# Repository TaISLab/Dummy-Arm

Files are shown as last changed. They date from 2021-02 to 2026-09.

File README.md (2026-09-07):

# Modular and sensorized dummy-arm

Desing of a sensorized dummy arm for human-robot interaction experiments.
The system icnludes a 3D printed arm with 10k linear rotary potentiometers and a DAQ based on a Arduino Mega which provides joint values at a rate of 100 Hz.
This repository includes both the STL for the arm components and the firmware dor the data acquisition system.

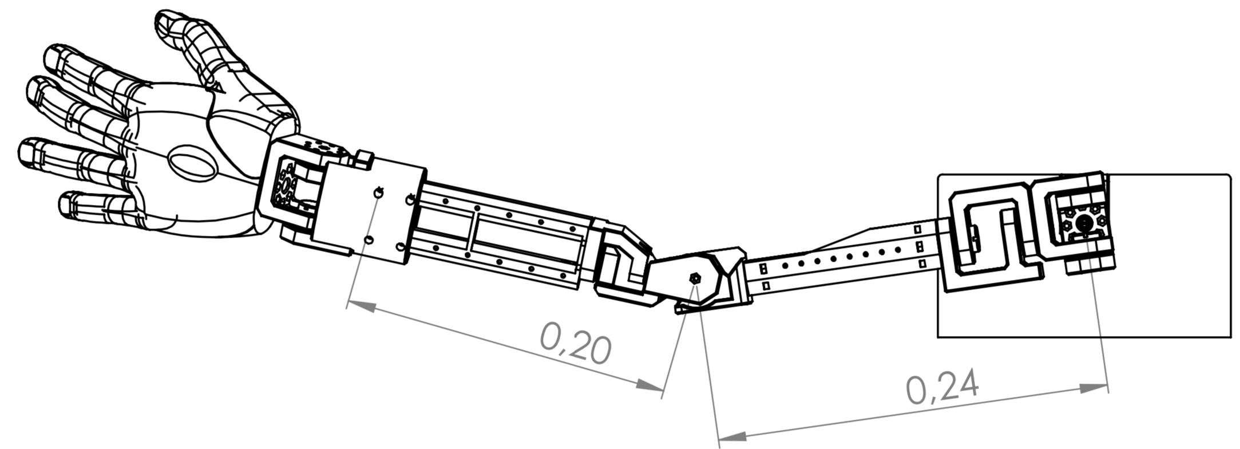
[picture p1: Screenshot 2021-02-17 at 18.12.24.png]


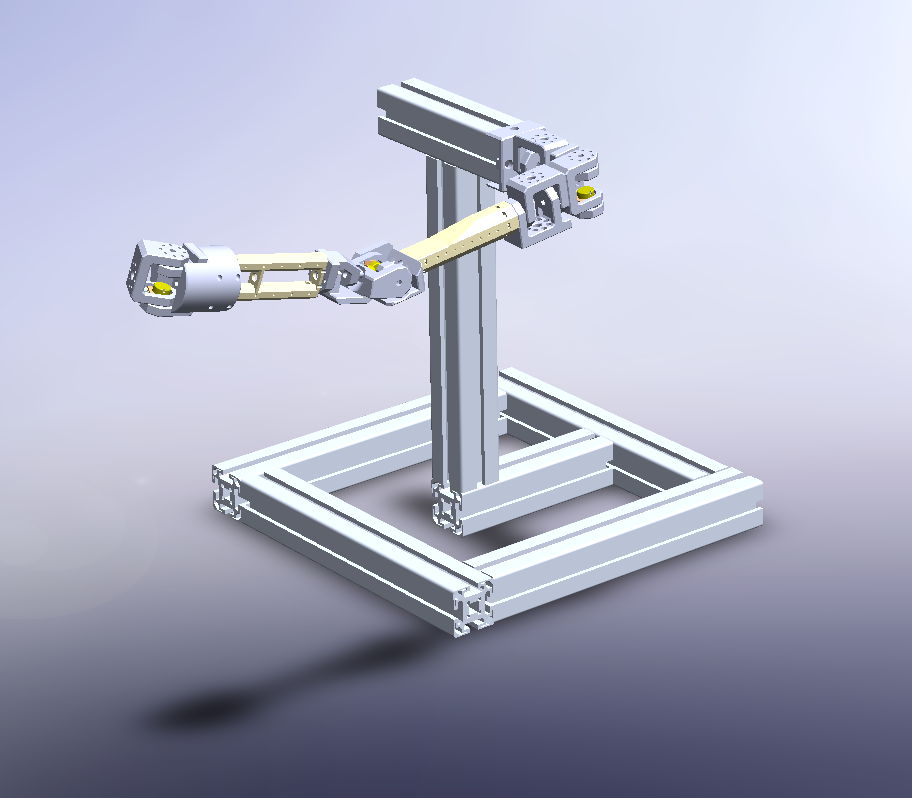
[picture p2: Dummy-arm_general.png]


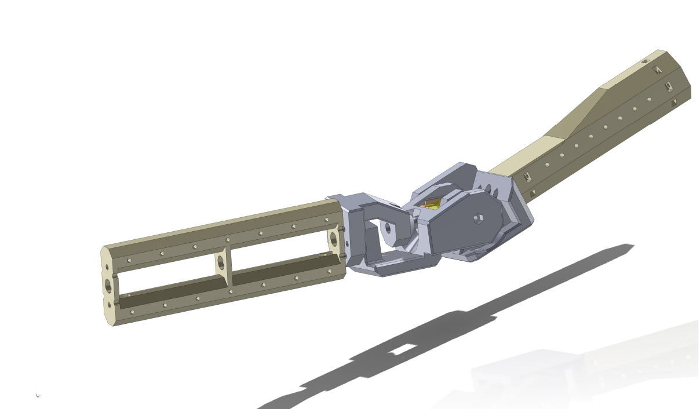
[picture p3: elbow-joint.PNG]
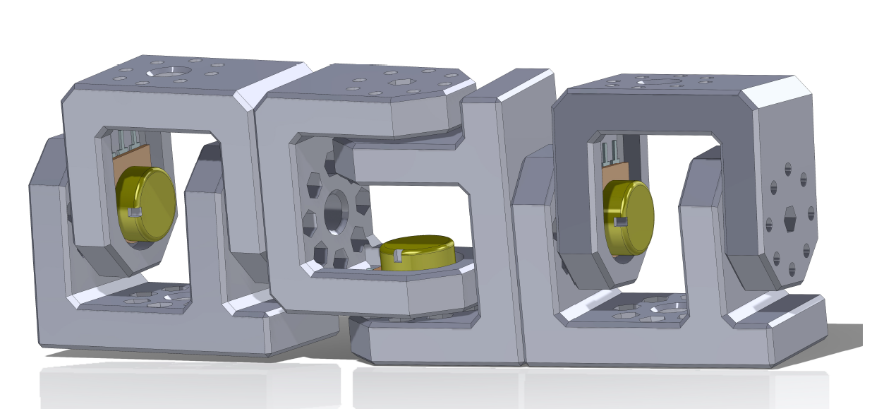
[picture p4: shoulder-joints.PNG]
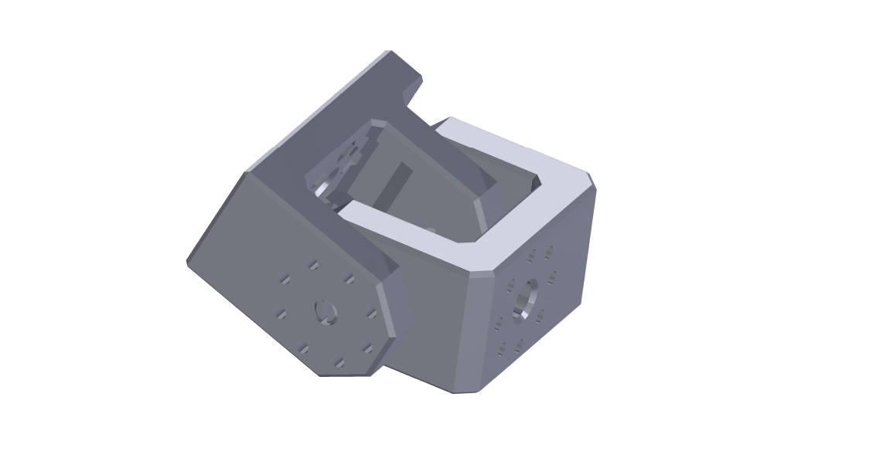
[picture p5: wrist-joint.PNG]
  

## Funding

This work is part of the project PID2021-127221OB-I00, funded by MICIU/AEI/10.13039/501100011033/FEDER, UE

<p align="center">
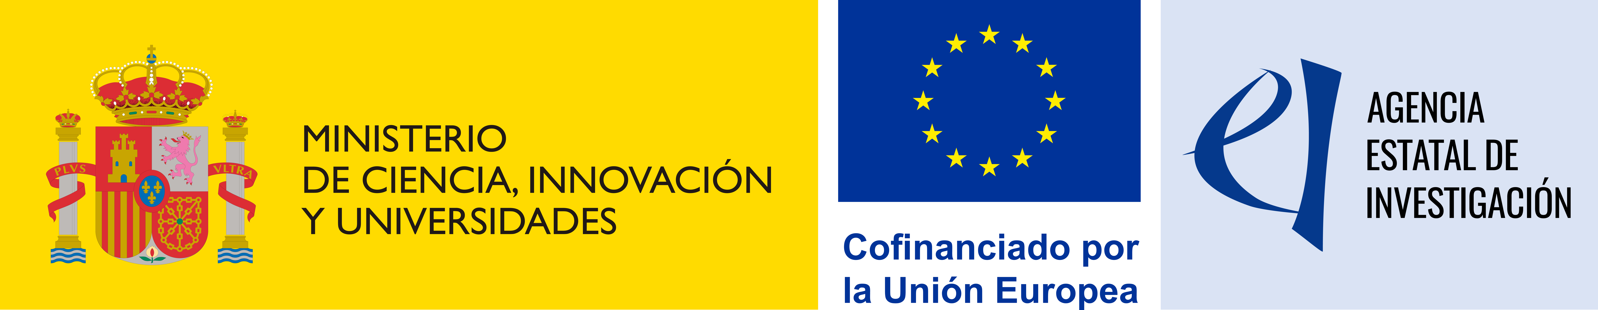
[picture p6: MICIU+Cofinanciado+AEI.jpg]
  
</p>

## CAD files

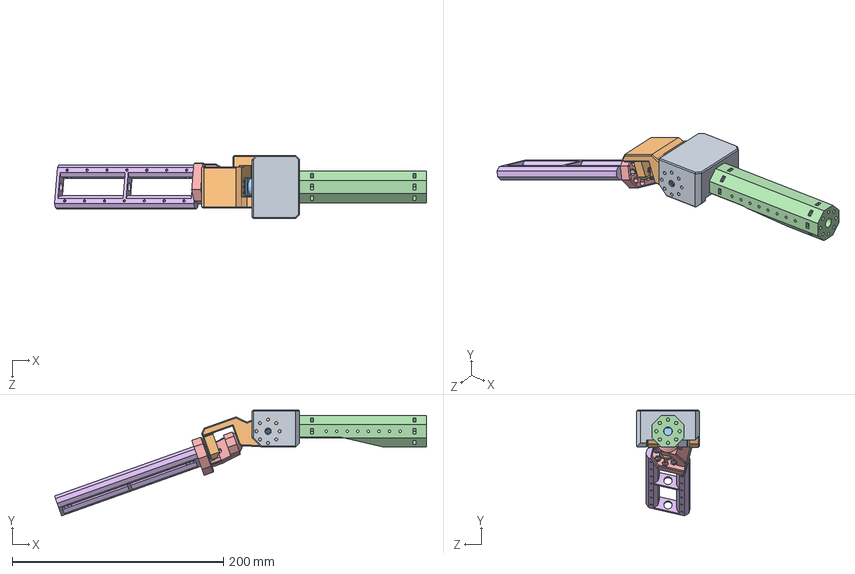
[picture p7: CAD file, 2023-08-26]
CAD/joint3.SLDASM
352.1 x 100.1 x 60.0 mm
joint3B
joint3A2
pot x 2
humero3
joint3C
radius-ulna3

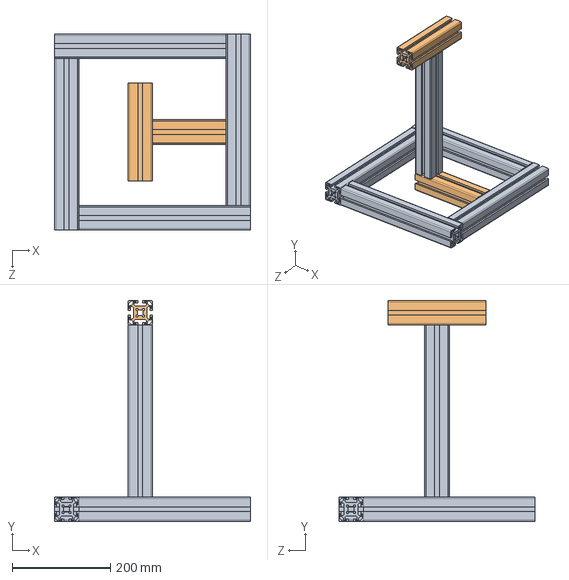
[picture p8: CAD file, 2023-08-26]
CAD/Stand/Stand.SLDASM
400.0 x 450.0 x 400.0 mm
Profile50x200 x 2
Profile50x350 x 5

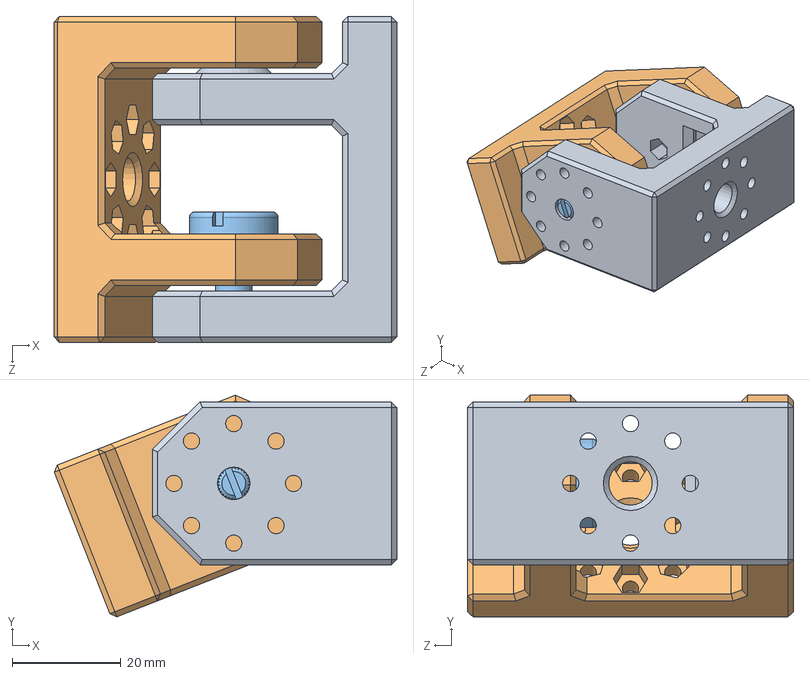
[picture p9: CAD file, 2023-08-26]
CAD/joint2.SLDASM
63.0 x 40.8 x 60.0 mm
jointB
jointA
pot

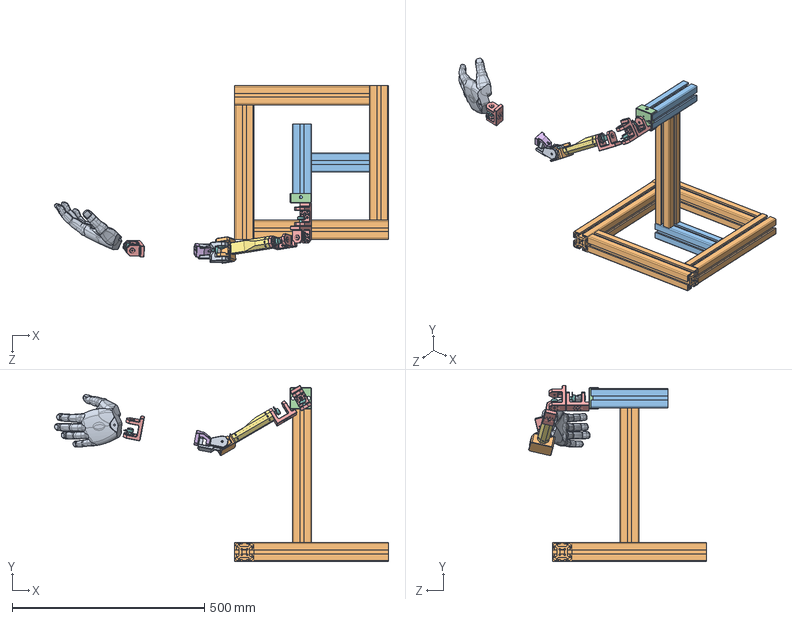
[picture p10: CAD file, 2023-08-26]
CAD/Left-human-arm.SLDASM
868.8 x 458.0 x 462.4 mm
joint3B
joint3A2
pot x 6
humero3
joint3C
jointB x 4
Soporte perfil hombro
Profile50x200 x 2
Profile50x350 x 5
mano

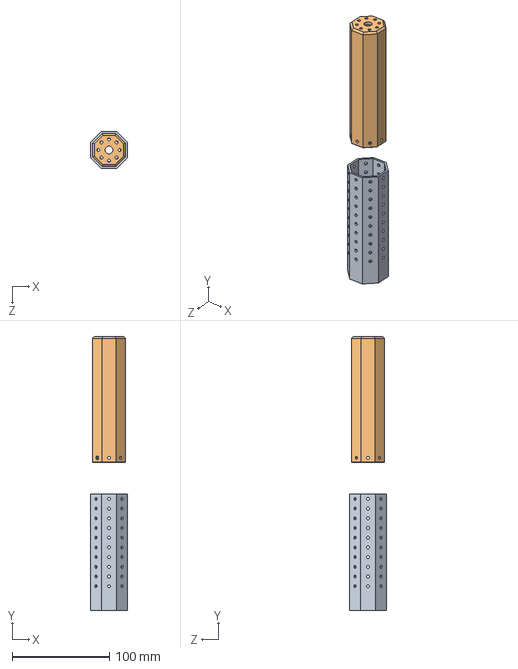
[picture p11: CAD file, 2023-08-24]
CAD/humero.SLDASM
38.0 x 282.3 x 38.0 mm
humeroA
humeroB

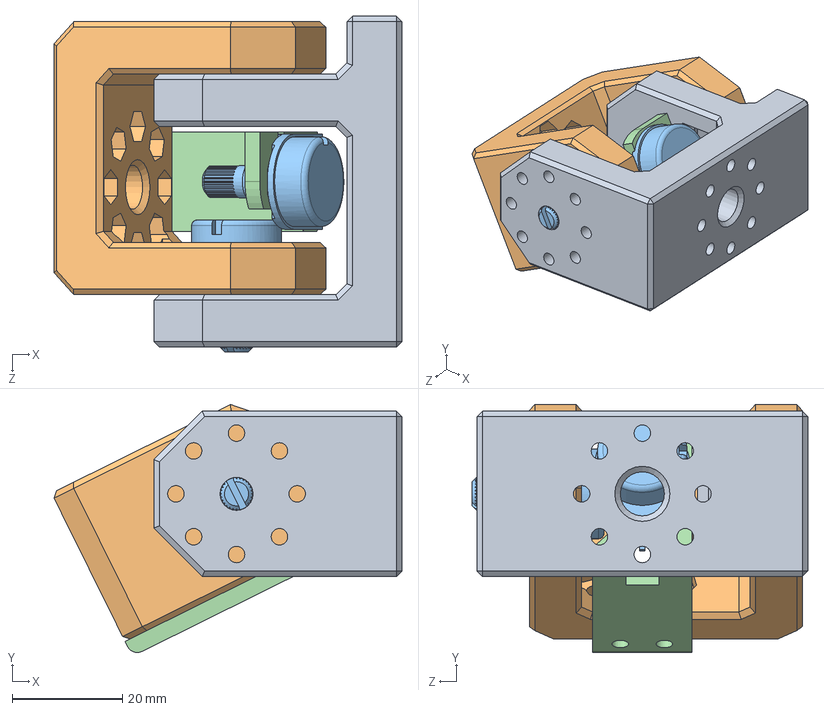
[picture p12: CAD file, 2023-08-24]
CAD/jointC.SLDASM
63.1 x 45.0 x 60.8 mm
jointB
jointA
pot x 2
soportepot

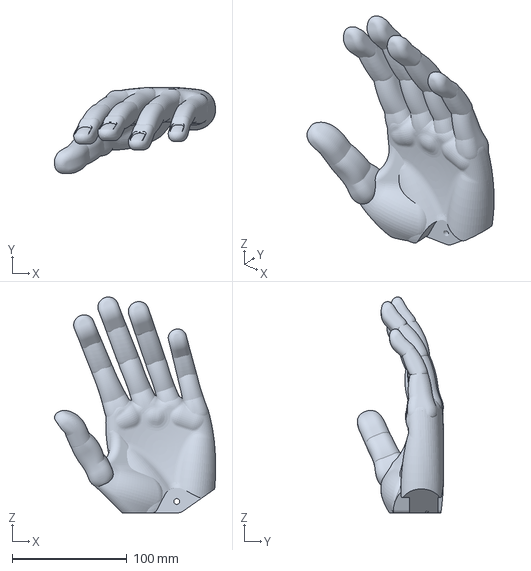
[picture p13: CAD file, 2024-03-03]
STL/mano 08.3mf
140.7 x 75.3 x 188.3 mm

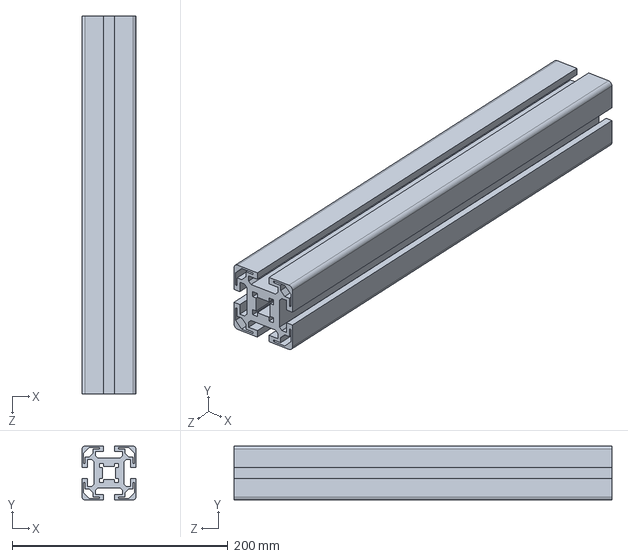
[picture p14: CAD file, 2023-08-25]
CAD/Stand/Profile50x350.SLDPRT
50.0 x 50.0 x 350.0 mm

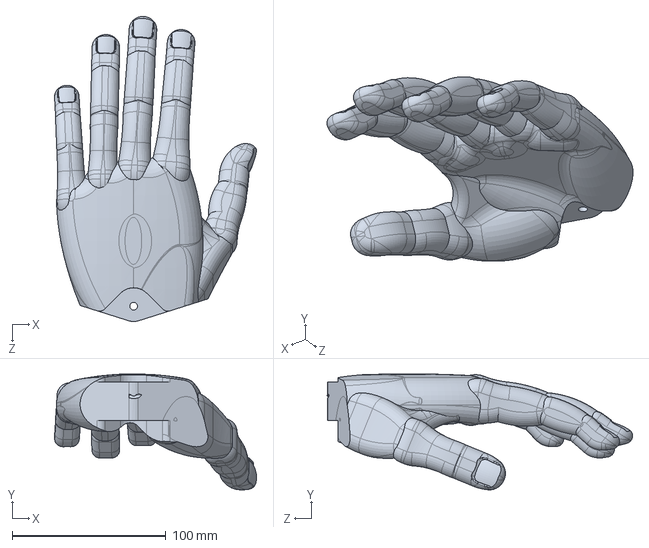
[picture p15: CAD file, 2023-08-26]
CAD/mano.SLDPRT
131.3 x 75.2 x 198.4 mm

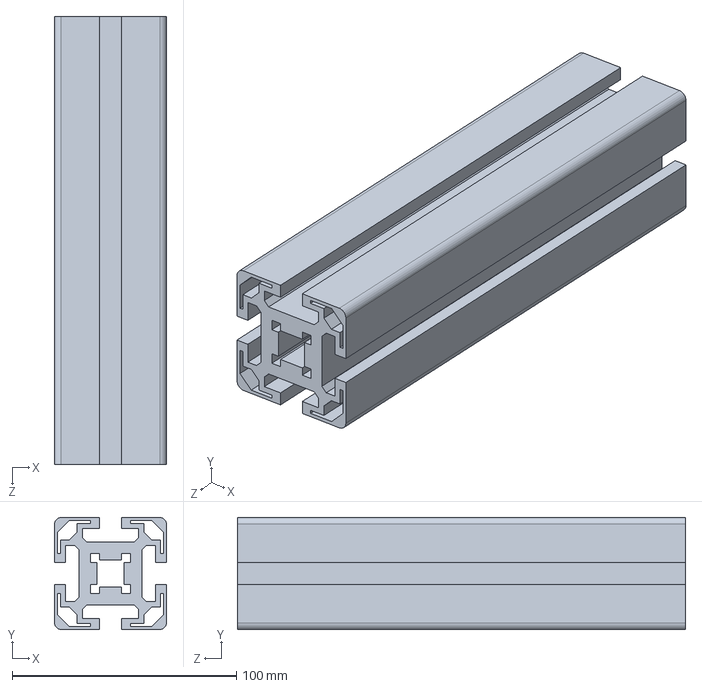
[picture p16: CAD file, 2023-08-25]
CAD/Stand/Profile50x200.SLDPRT
50.0 x 50.0 x 200.0 mm

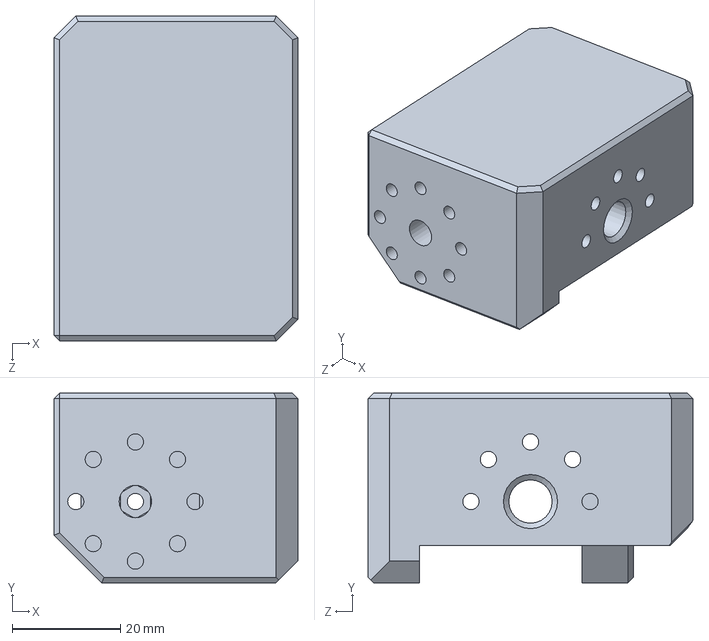
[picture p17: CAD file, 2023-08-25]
CAD/joint3B.SLDPRT
45.0 x 35.0 x 60.0 mm

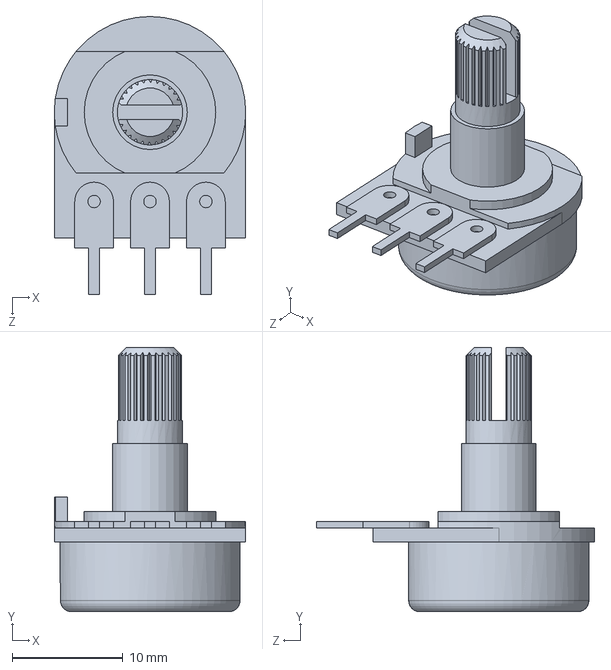
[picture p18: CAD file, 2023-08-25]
CAD/pot.SLDPRT
17.3 x 23.9 x 25.1 mm

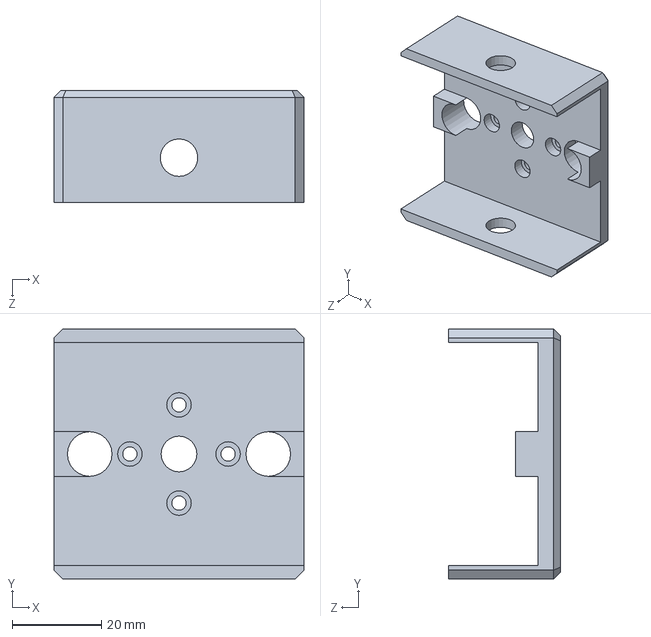
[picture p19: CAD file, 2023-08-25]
CAD/Soporte perfil hombro.SLDPRT
56.0 x 56.0 x 25.0 mm

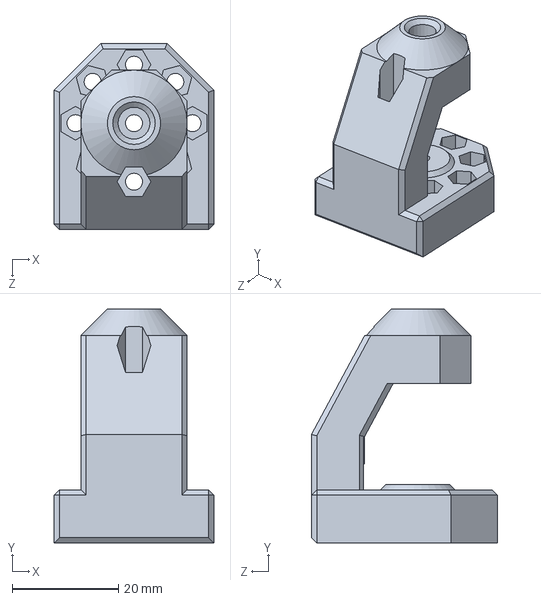
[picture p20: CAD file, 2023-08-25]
CAD/joint3C.SLDPRT
30.0 x 44.0 x 35.0 mm

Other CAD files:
CAD/joint.SLDASM
CAD/joint3A2.SLDPRT
CAD/humero3.SLDPRT
CAD/jointB.SLDPRT
CAD/Pieza3.SLDPRT
CAD/Soporte.SLDPRT
CAD/cubitoA.SLDPRT
CAD/cubitoB.SLDPRT
CAD/humero2.SLDPRT
CAD/humeroA.SLDPRT
CAD/humeroB.SLDPRT
CAD/humeroXA.SLDPRT
CAD/humeroXB.SLDPRT
CAD/joint3A.SLDPRT
CAD/jointA.SLDPRT
CAD/jointA2.SLDPRT
CAD/jointB2.SLDPRT
CAD/jointC2.SLDPRT
CAD/radius-ulna2.SLDPRT
CAD/radius-ulna3.SLDPRT
CAD/soportepot.SLDPRT
CAD/suplemento-humero3.SLDPRT
CAD/wrist.SLDPRT
STL/Soporte perfil hombro.3mf
STL/Soporte perfil hombro.STL
STL/humero2.STL
STL/humero3.STL
STL/humeroA.STL
STL/humeroB.STL
STL/humeroXA.STL
STL/humeroXB.STL
STL/joint3A2.STL
STL/joint3B.STL
STL/joint3C.STL
STL/jointA.STL
STL/jointA2.STL
STL/jointB.STL
STL/jointB2.STL
STL/mano.3mf
STL/radius-ulna2.STL
STL/radius-ulna3.STL
STL/suplemento-humero3.STL
STL/wrist.STL

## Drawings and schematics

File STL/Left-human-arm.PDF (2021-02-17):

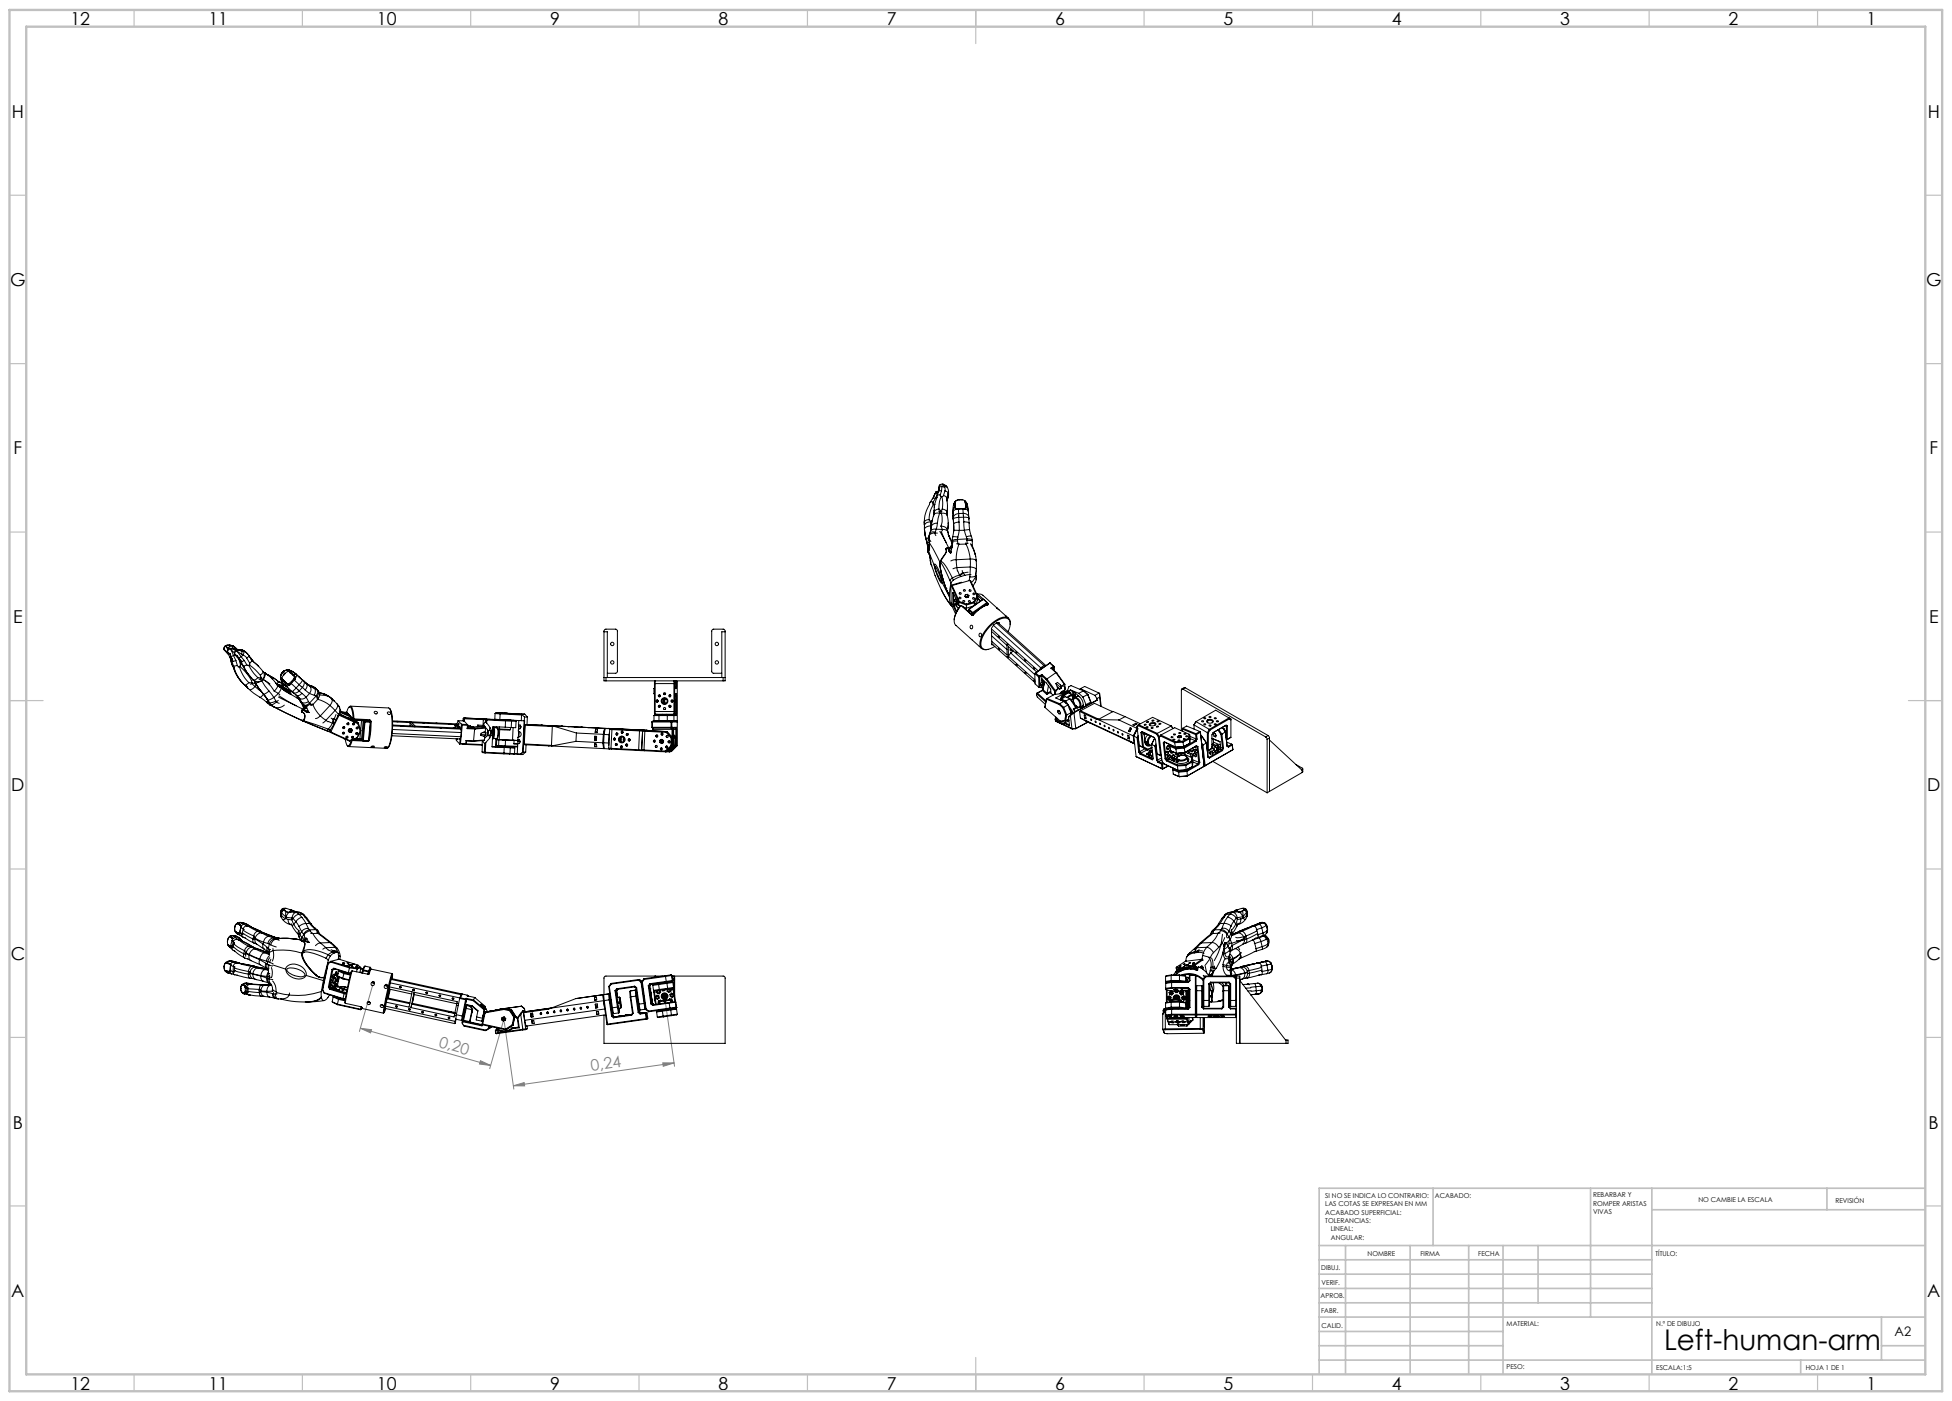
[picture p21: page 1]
ESCALA:1:5; HOJA 1 DE 1

SI NO SE INDICA LO CONTRARIO: LAS COTAS SE EXPRESAN EN MM ACABADO SUPERFICIAL: TOLERANCIAS: LINEAL: ANGULAR: | ACABADO: | REBARBAR Y ROMPER ARISTAS VIVAS | NO CAMBIE LA ESCALA | REVISIÓN

NOMBRE | FIRMA | FECHA | | | | TÍTULO:

DIBUJ.
VERIF.
APROB.
FABR.
CALID. | | | | MATERIAL: | N.º DE DIBUJO Left-human-arm | A2

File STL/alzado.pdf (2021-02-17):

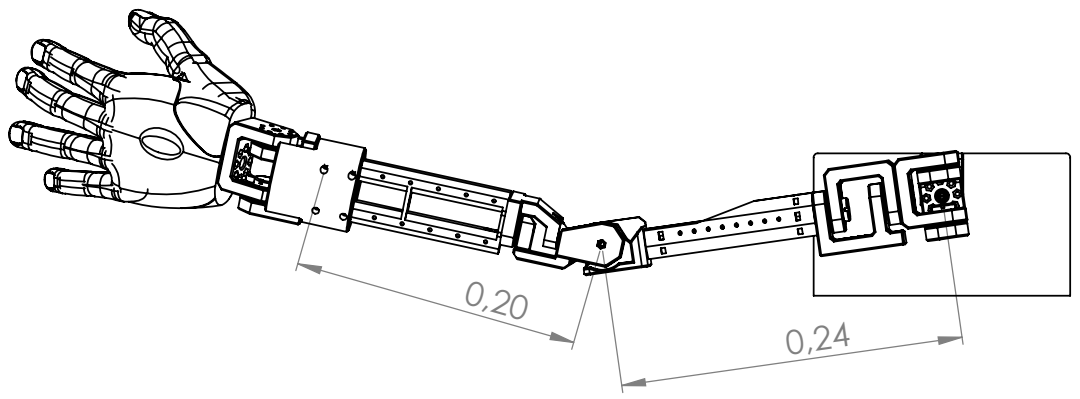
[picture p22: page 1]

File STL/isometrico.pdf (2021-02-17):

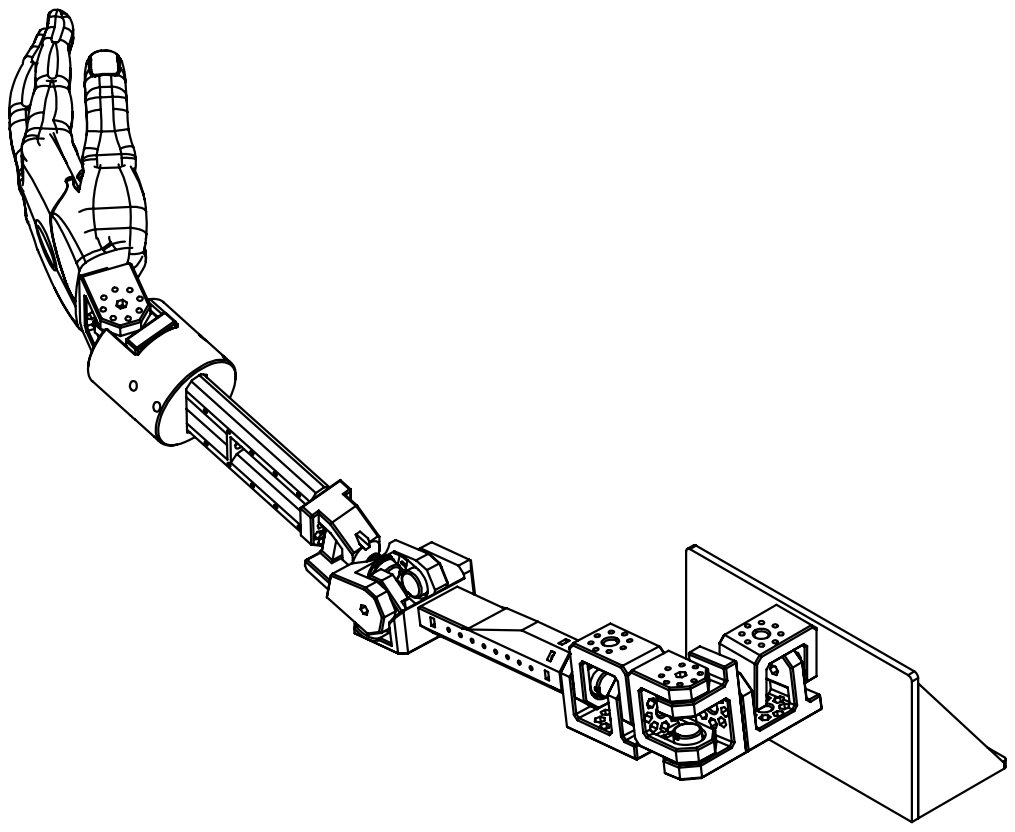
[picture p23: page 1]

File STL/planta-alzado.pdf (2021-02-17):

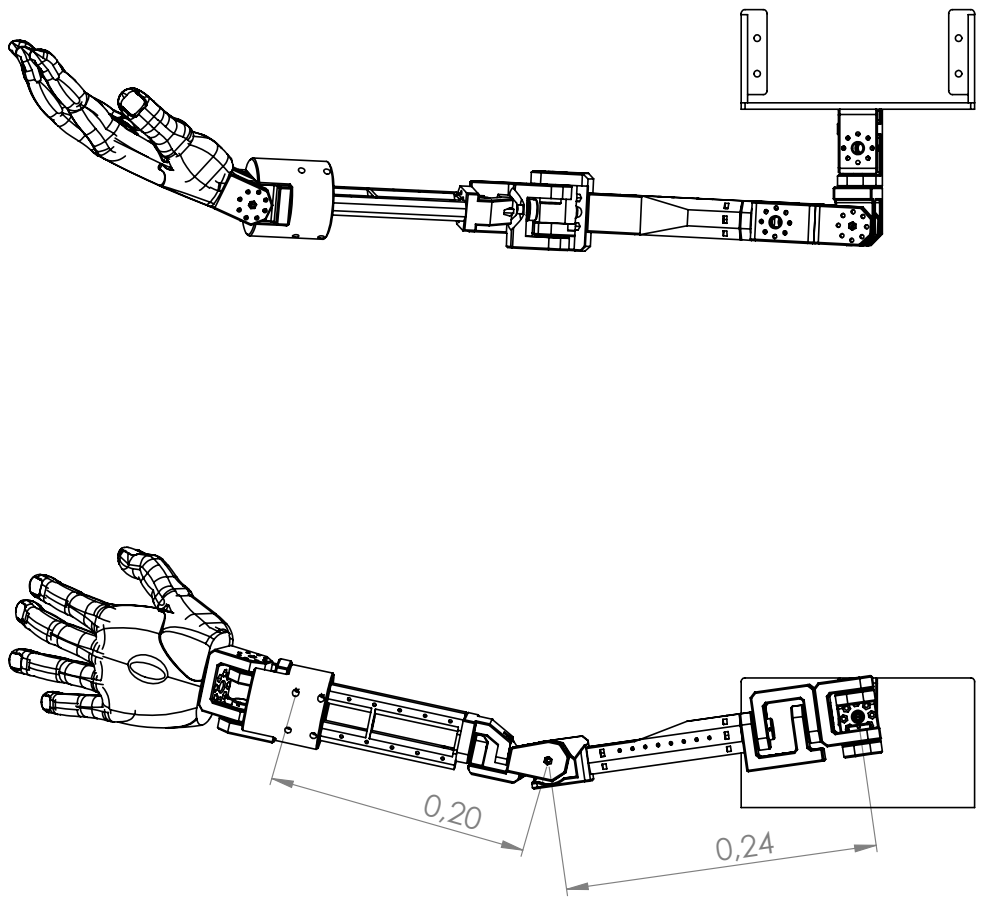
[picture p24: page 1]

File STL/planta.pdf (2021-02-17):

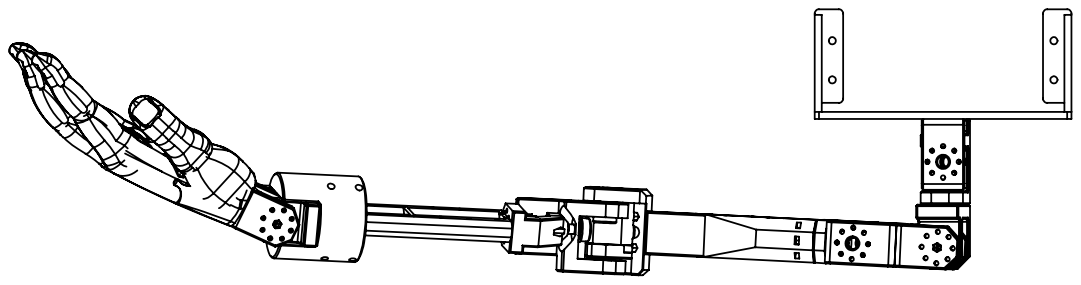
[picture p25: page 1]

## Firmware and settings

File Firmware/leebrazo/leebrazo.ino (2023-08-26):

// TaISLAb 
// https://github.com/TaISLab/dummyarm
//
// DAQ for the dummy ARM
// Use Arduino Mega
//


// These constants won't change. They're used to give names to the pins used:
const int analogInPin = A0;  // Analog input pin that the potentiometer is attached to
const int analogOutPin = 9; // Analog output pin that the LED is attached to

int sensorValue = 0;        // value read from the pot
int outputValue = 0;        // value output to the PWM (analog out)

long nextt, t;

#define periodo 10
#define DOF 6

int input[DOF]; // ADC input readings
double angle[DOF]; // Joint angle values

int    inputmin[DOF] = {    444,   83,    176,  537,   180,  335};
double anglemin[DOF] = {     0,    0,    0,    0,  -90,  -45};
int    inputmax[DOF] = { 795, 452,   893,  175,  874, 652};
double anglemax[DOF] = {   90,  90,   180,   90,   90,   45};

void setup() {
  // initialize serial communications at 9600 bps:
  Serial.begin(250000);
  nextt=millis();
}


double fmap(double input, double inputmin, double inputmax, double outputmin, double outputmax)
{
  return outputmin+((input-inputmin)/(inputmax-inputmin))*(outputmax-outputmin); 
}



void loop() {

  while ((t=millis())<nextt);
  nextt+=periodo; 
  int n;
  // read the analog in value:
  input[0] = analogRead(A6);
  input[1] = analogRead(A4);
  input[2] = analogRead(A5);
  input[3] = analogRead(A0);
  input[4] = analogRead(A2);
  input[5] = analogRead(A1);
  // map it to the range of the analog out:
  for (n=0; n<DOF; n++) angle[n] = fmap(input[n], inputmin[n], inputmax[n], anglemin[n], anglemax[n]);
  // change the analog out value:
  
  Serial.print(t);    // Timestamp
  for (n=0; n<DOF; n++) {
    Serial.print(",     ");
   // Serial.print(input[n]);
    Serial.print(angle[n]);
  }
  Serial.println("");


}

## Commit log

2023-08-24 Add files via upload
    Adding PNG of elbow, wrist and shoulder joints.
2023-08-24 Uploaded SolidWorks Files
    [Ensamblaje2.SLDASM, Left-human-arm.SLDASM, Pieza3.SLDPRT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]
2023-08-25 Added shoulder support
    [Left-human-arm.SLDASM, Soporte perfil hombro.3mf, Soporte perfil hombro.SLDPRT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]
2023-08-25 Cleaned and general review
    [Left-human-arm.SLDASM, Profile50x200.SLDPRT, Profile50x350.SLDPRT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]
2023-08-26 Repo folder improvement
    [Ensamblaje2.SLDASM, Left-human-arm.SLDASM, Pieza3.SLDPRT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]
2023-08-26 Added a Hand
    [Left-human-arm.SLDASM, joint2.SLDASM, joint3.SLDASM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]
2023-12-12 Nodo ROS2 publicador de datos de los potenciómetros
2024-03-03 Nueva mano
    [mano 08.3mf, mano.3mf]
2026-09-07 docs: add arm images to README and centered funding logo
    Claude-Session: https://claude.ai/code/session_018r1A7UgVps2DocQbkgGdvK
